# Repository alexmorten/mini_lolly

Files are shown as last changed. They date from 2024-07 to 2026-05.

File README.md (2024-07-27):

# Mini Lolly

## Run the Simulator

Run any kind of static file server in the repo root to run the simulator.
For example, you can use the following commands as a server:

```bash
python -m http.server 8000
# or 
ruby -run -ehttpd . -p8000
```

Access the simulator by visiting http://localhost:8000 in your browser.

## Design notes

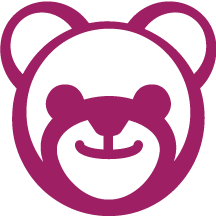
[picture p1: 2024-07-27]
simulator/img/teddyhead-maroontransparent.png

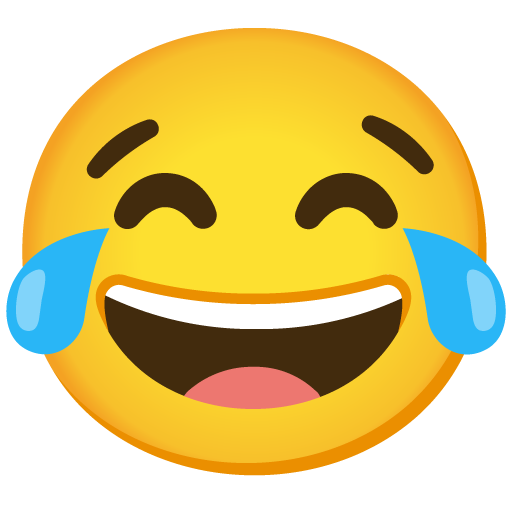
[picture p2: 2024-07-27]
simulator/img/face-with-tears-of-joy.png

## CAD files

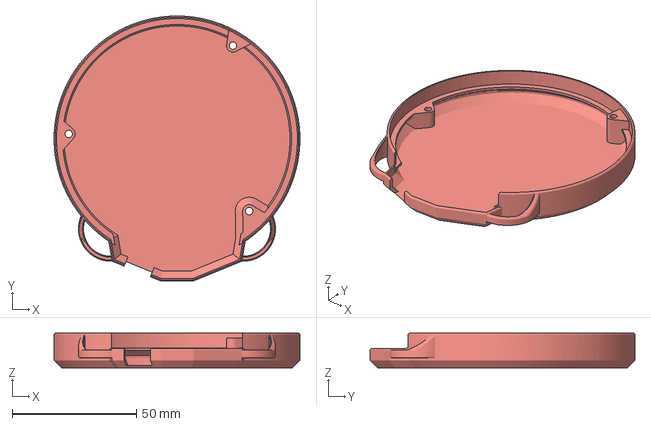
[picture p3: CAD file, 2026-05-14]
printing/housing.3mf
98.8 x 106.5 x 14.0 mm

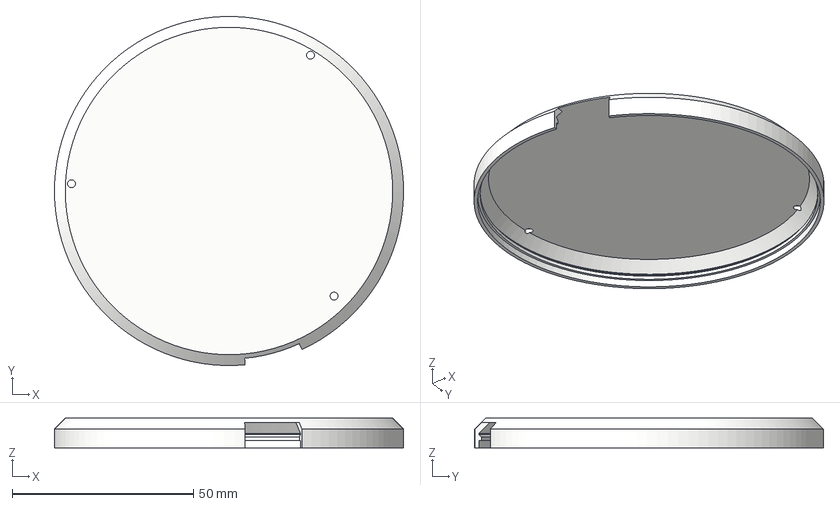
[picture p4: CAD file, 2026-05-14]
printing/diffuser.3mf
96.4 x 96.4 x 8.20 mm

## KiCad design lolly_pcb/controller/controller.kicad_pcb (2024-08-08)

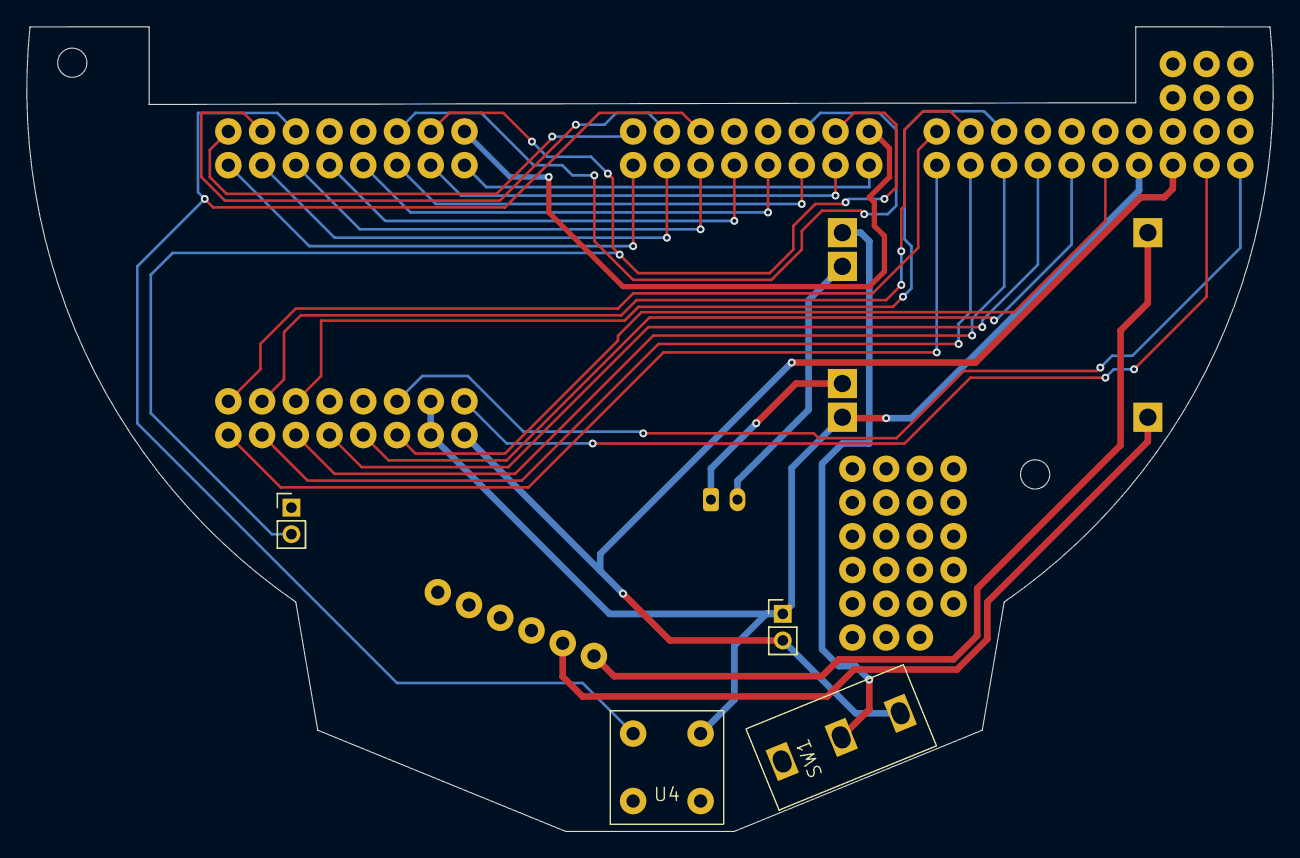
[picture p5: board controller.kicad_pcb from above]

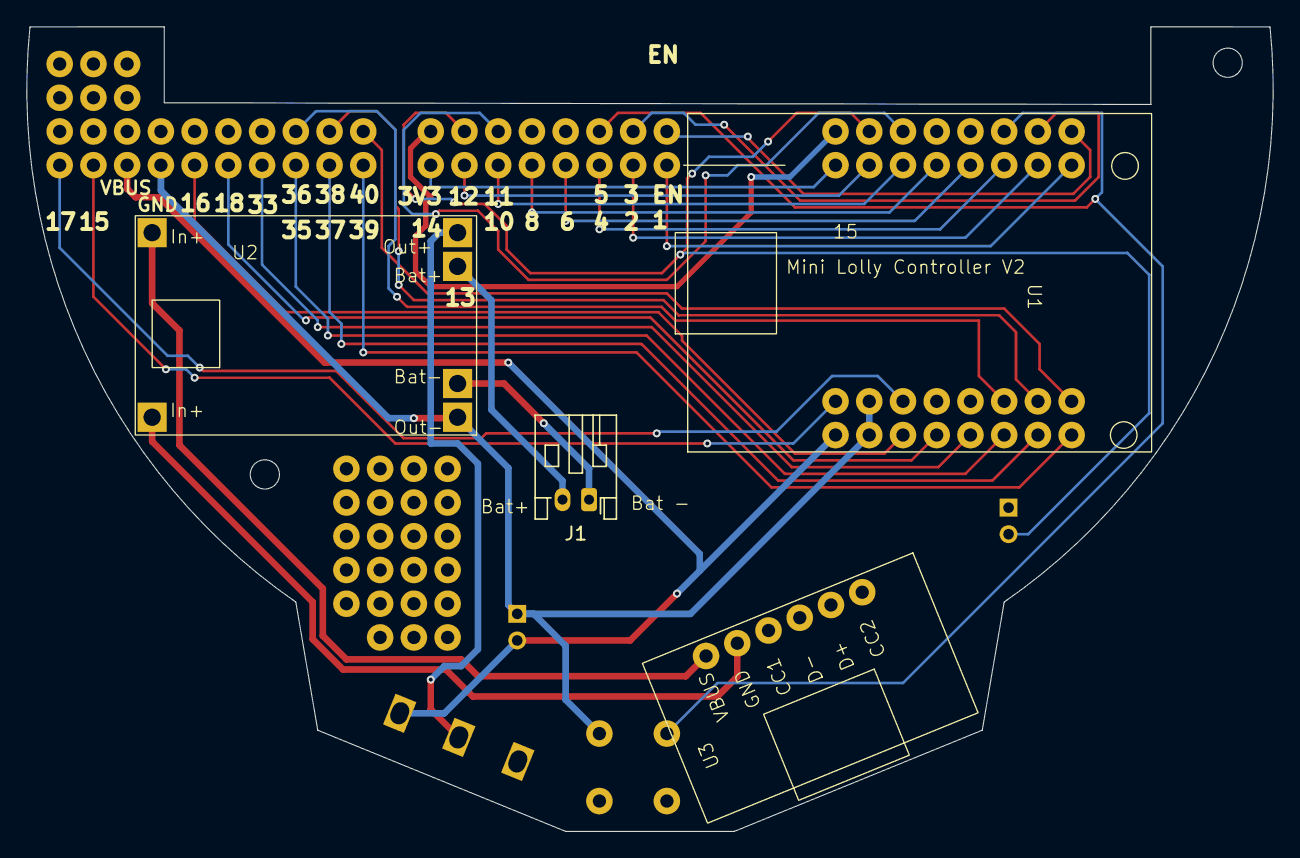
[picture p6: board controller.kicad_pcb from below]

Board: 2 copper layers, 93.8 x 60.6 mm, 6 parts (4 on the bottom side), 8 nets.

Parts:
J1: Conn_01x02_Pin; JST_PH_S2B-PH-K_1x02_P2.00mm_Horizontal
SW1: SW_SPDT; 1P2T SPDT RUNCCI-YUN
U1: ESP32-S2-MINI-1; esp32 s2-mini dev board
U2: tp4056 module
U3: usb-c 5v breakout
U4: small thoughhole button

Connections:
5: U1.5 (GPIO5/ADC1_CH4), U4.1 (In1)
Bat+: J1.2, U2.5 (Bat_+)
Bat-: J1.1, U2.6 (Bat_-)
GND: U1.GND, U2.4 (Out_-), U4.3 (Out1)
unnamed: SW1.2 (B), U2.3 (Out_+)
unnamed: U2.1 (In_+), U3.1 (VBUS)
unnamed: U2.2 (In_-), U3.2 (GND)
VBUS: SW1.3 (C), U1.VBUS

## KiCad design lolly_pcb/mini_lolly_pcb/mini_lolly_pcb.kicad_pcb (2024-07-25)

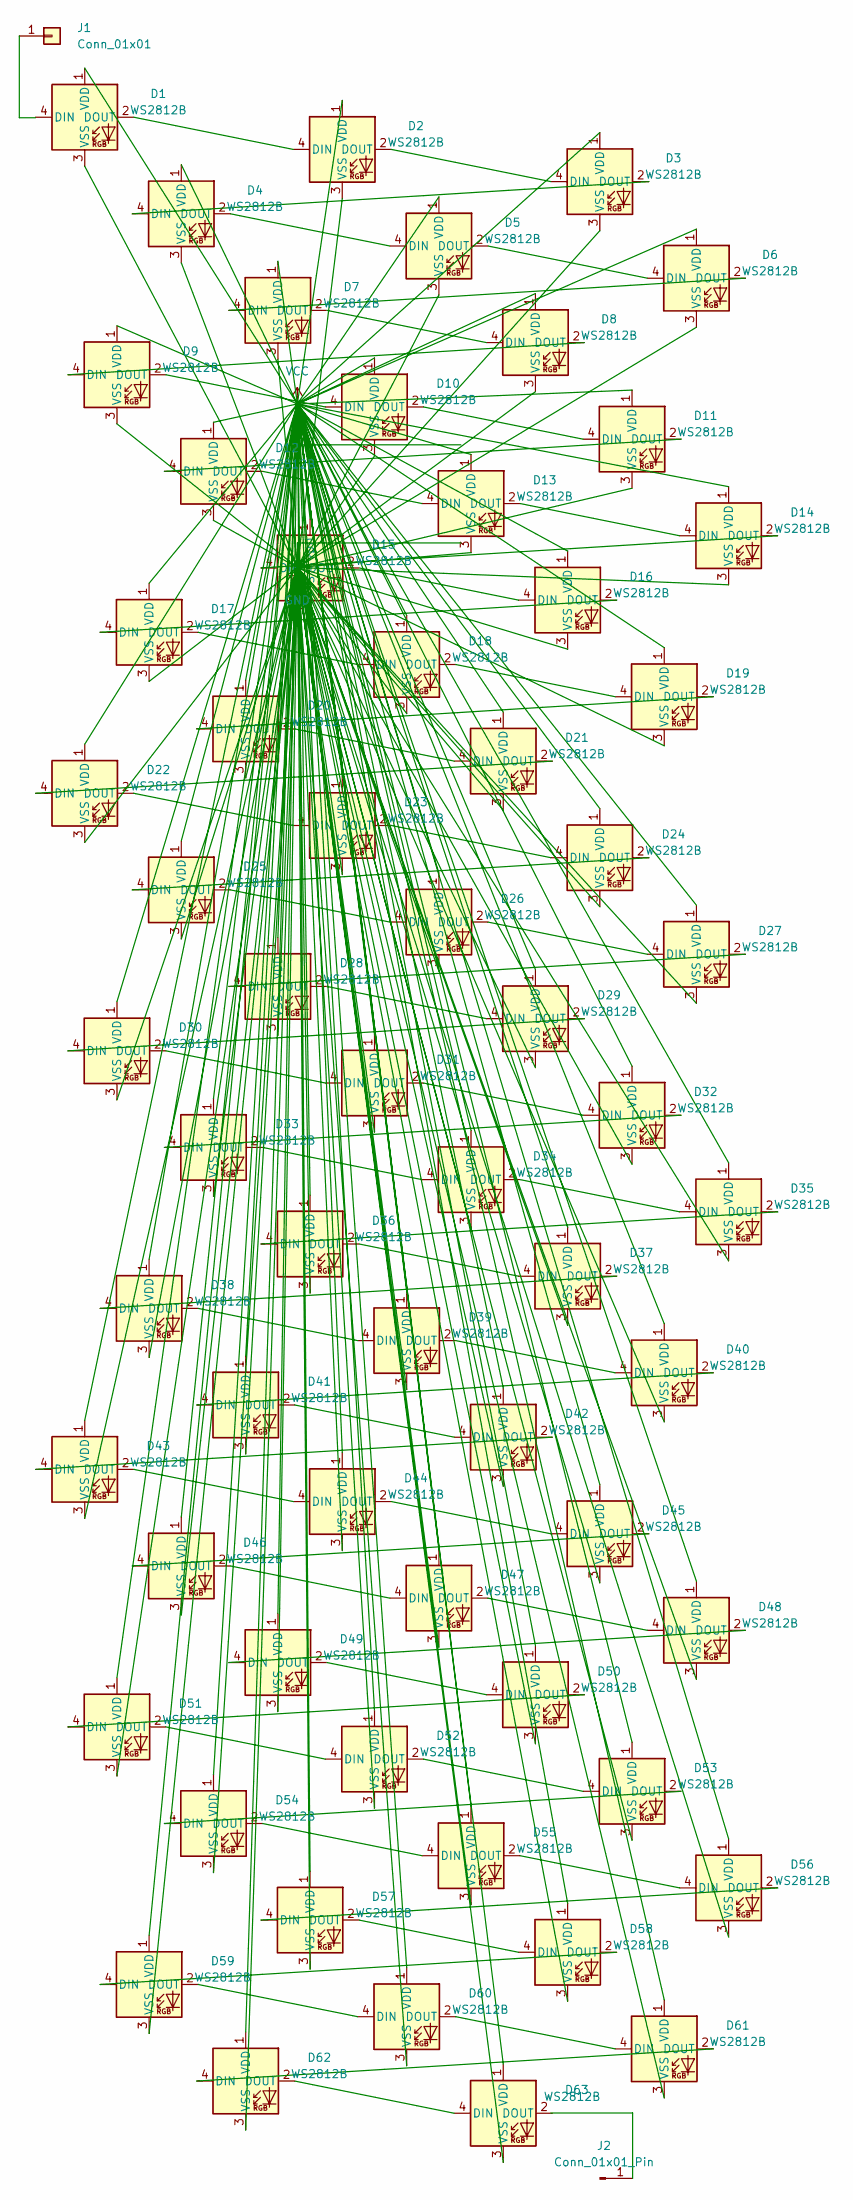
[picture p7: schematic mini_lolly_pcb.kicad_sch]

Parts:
D1, D2, D3, D4, D5, D6, D7, D8, D9, D10, D11, D12, D13, D14, D15, D16, D17, D18, D19, D20, D21, D22, D23, D24, D25, D26, D27, D28, D29, D30, D31, D32, D33, D34, D35, D36, D37, D38, D39, D40, D41, D42, D43, D44, D45, D46, D47, D48, D49, D50, D51, D52, D53, D54, D55, D56, D57, D58, D59, D60, D61, D62, D63: WS2812B; LED_WS2812B_PLCC4_5.0x5.0mm_P3.2mm
J1: Conn_01x01
J2: Conn_01x01_Pin

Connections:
unnamed: D1.2 (DOUT), D2.4 (DIN)
unnamed: D2.2 (DOUT), D3.4 (DIN)
unnamed: D3.2 (DOUT), D4.4 (DIN)
unnamed: D4.2 (DOUT), D5.4 (DIN)
unnamed: D5.2 (DOUT), D6.4 (DIN)
unnamed: D6.2 (DOUT), D7.4 (DIN)
unnamed: D7.2 (DOUT), D8.4 (DIN)
unnamed: D8.2 (DOUT), D9.4 (DIN)
unnamed: D9.2 (DOUT), D10.4 (DIN)
unnamed: D10.2 (DOUT), D11.4 (DIN)
unnamed: D11.2 (DOUT), D12.4 (DIN)
unnamed: D12.2 (DOUT), D13.4 (DIN)
unnamed: D13.2 (DOUT), D14.4 (DIN)
unnamed: D14.2 (DOUT), D15.4 (DIN)
unnamed: D15.2 (DOUT), D16.4 (DIN)
unnamed: D16.2 (DOUT), D17.4 (DIN)
unnamed: D17.2 (DOUT), D18.4 (DIN)
unnamed: D18.2 (DOUT), D19.4 (DIN)
unnamed: D19.2 (DOUT), D20.4 (DIN)
unnamed: D20.2 (DOUT), D21.4 (DIN)
unnamed: D21.2 (DOUT), D22.4 (DIN)
unnamed: D22.2 (DOUT), D23.4 (DIN)
unnamed: D23.2 (DOUT), D24.4 (DIN)
unnamed: D24.2 (DOUT), D25.4 (DIN)
unnamed: D25.2 (DOUT), D26.4 (DIN)
unnamed: D26.2 (DOUT), D27.4 (DIN)
unnamed: D27.2 (DOUT), D28.4 (DIN)
unnamed: D28.2 (DOUT), D29.4 (DIN)
unnamed: D29.2 (DOUT), D30.4 (DIN)
unnamed: D30.2 (DOUT), D31.4 (DIN)
unnamed: D31.2 (DOUT), D32.4 (DIN)
unnamed: D32.2 (DOUT), D33.4 (DIN)
unnamed: D33.2 (DOUT), D34.4 (DIN)
unnamed: D34.2 (DOUT), D35.4 (DIN)
unnamed: D35.2 (DOUT), D36.4 (DIN)
unnamed: D36.2 (DOUT), D37.4 (DIN)
unnamed: D37.2 (DOUT), D38.4 (DIN)
unnamed: D38.2 (DOUT), D39.4 (DIN)
unnamed: D39.2 (DOUT), D40.4 (DIN)
unnamed: D40.2 (DOUT), D41.4 (DIN)
unnamed: D41.2 (DOUT), D42.4 (DIN)
unnamed: D42.2 (DOUT), D43.4 (DIN)
unnamed: D43.2 (DOUT), D44.4 (DIN)
unnamed: D44.2 (DOUT), D45.4 (DIN)
unnamed: D45.2 (DOUT), D46.4 (DIN)
unnamed: D46.2 (DOUT), D47.4 (DIN)
unnamed: D47.2 (DOUT), D48.4 (DIN)
unnamed: D48.2 (DOUT), D49.4 (DIN)
unnamed: D49.2 (DOUT), D50.4 (DIN)
unnamed: D50.2 (DOUT), D51.4 (DIN)
unnamed: D51.2 (DOUT), D52.4 (DIN)
unnamed: D52.2 (DOUT), D53.4 (DIN)
unnamed: D53.2 (DOUT), D54.4 (DIN)
unnamed: D54.2 (DOUT), D55.4 (DIN)
unnamed: D55.2 (DOUT), D56.4 (DIN)
unnamed: D56.2 (DOUT), D57.4 (DIN)
unnamed: D57.2 (DOUT), D58.4 (DIN)
unnamed: D58.2 (DOUT), D59.4 (DIN)
unnamed: D59.2 (DOUT), D60.4 (DIN)
unnamed: D60.2 (DOUT), D61.4 (DIN)
unnamed: D61.2 (DOUT), D62.4 (DIN)
unnamed: D62.2 (DOUT), D63.4 (DIN)

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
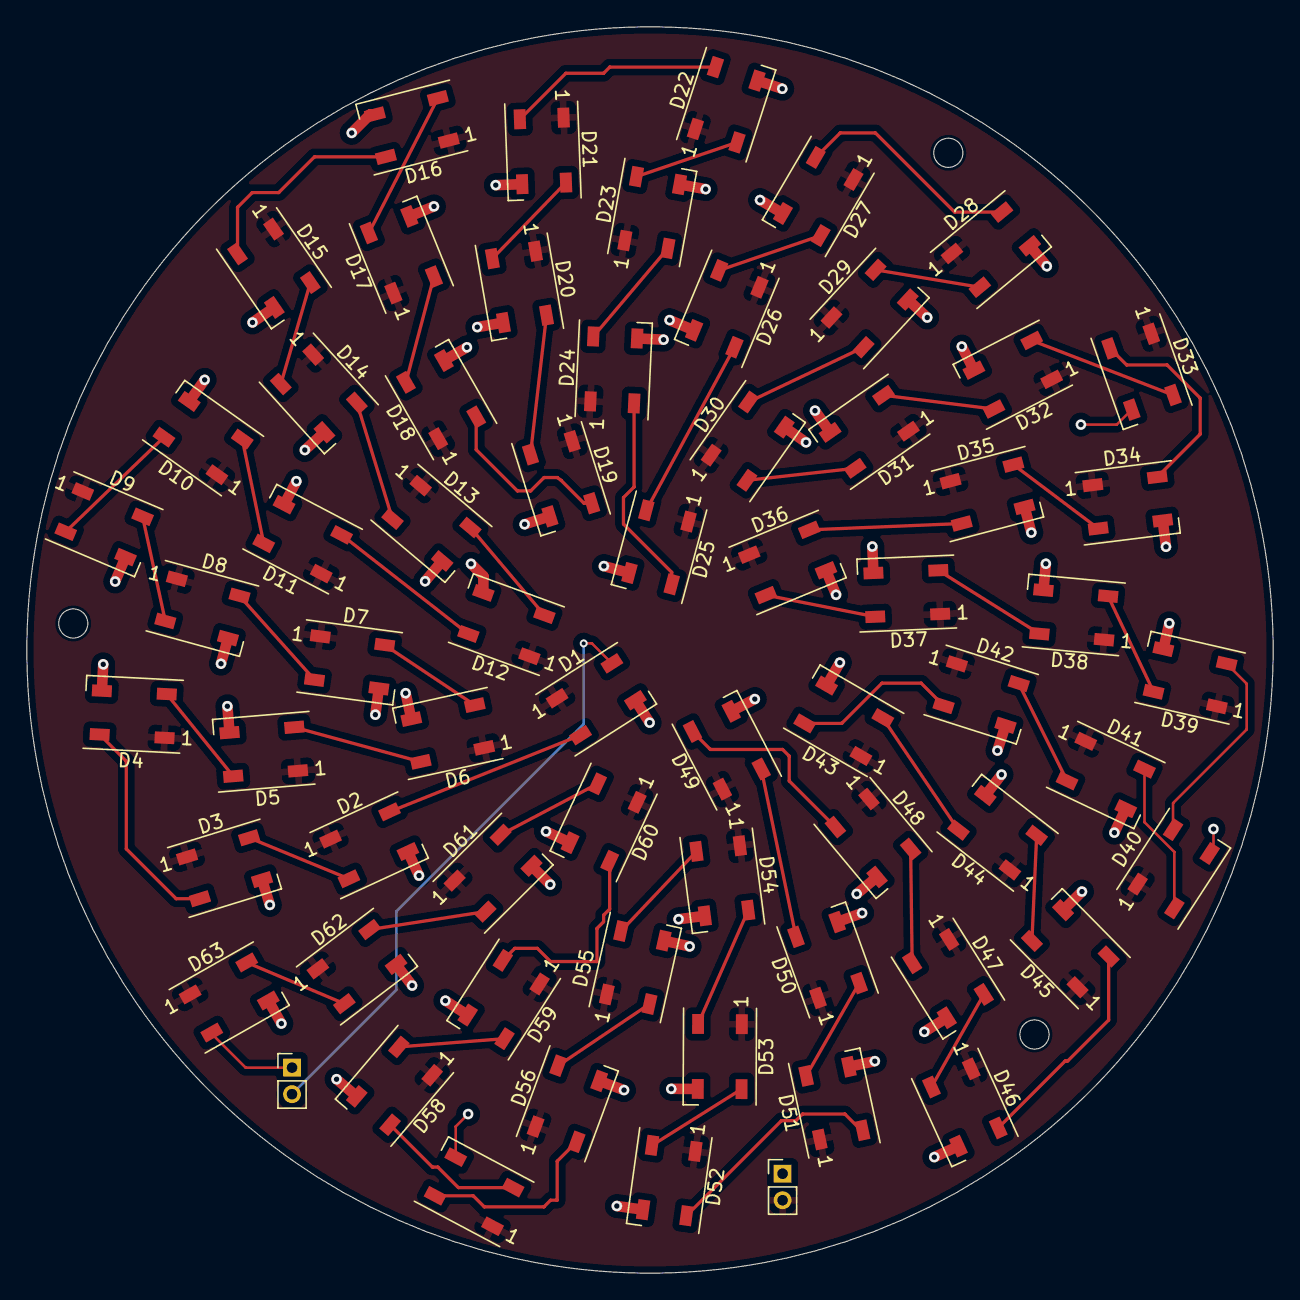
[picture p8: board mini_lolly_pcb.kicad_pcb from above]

Board: 2 copper layers, 94.0 x 94.0 mm, 63 parts (0 on the bottom side), 64 nets.

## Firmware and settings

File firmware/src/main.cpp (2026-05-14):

#include "FastLED.h"
#include "led_config.h"
#include "animations/twinkle_fox.h"
#include "animations/fire2012.h"
#include "animations/cylon.h"
#include "animations/demo_reel.h"
#include "animations/rings.h"
#include "animations/polar_rings.h"

// Replace with your network credentials
const char *ssid = "MiniLolly Manfred";
const char *password = "Lumos2024";

#define VOLTS 5
#define MAX_MA 200

#define NUM_BUTTONS 2
#define LED_BOARD 15
int buttonPins[NUM_BUTTONS] = {0, 5};

#define ARRAY_SIZE(A) (sizeof(A) / sizeof((A)[0]))

CRGBArray<NUM_LEDS> leds;

uint8_t brightness = 15;

void setBrightness(uint8_t b) {
    brightness = constrain(b, 1, 255);
    FastLED.setBrightness(brightness);
}

int buttonStates[NUM_BUTTONS] = {LOW};
int lastButtonStates[NUM_BUTTONS] = {LOW};
unsigned long lastDebounceTimes[NUM_BUTTONS] = {0};
String buttonNames[NUM_BUTTONS] = {"Board"};

#define debounceDelay 50

bool checkButton(int buttonIndex)
{
    bool buttonPressed = false;
    // read the state of the switch into a local variable:
    int reading = digitalRead(buttonPins[buttonIndex]);

    // check if the button has been pressed (i.e., reading is different from lastButtonState)
    if (reading != lastButtonStates[buttonIndex])
    {
        // reset the debouncing timer
        lastDebounceTimes[buttonIndex] = millis();
    }

    if ((millis() - lastDebounceTimes[buttonIndex]) > debounceDelay)
    {
        // whatever the reading is at, it's been there for longer than the debounce delay
        // so take it as the actual current state:
        if (reading != buttonStates[buttonIndex])
        {
            buttonStates[buttonIndex] = reading;

            // only toggle the LED if the new button state is HIGH
            if (buttonStates[buttonIndex] == LOW)
            {
                Serial.print("button ");
                Serial.print(buttonNames[buttonIndex]);
                Serial.println(" pressed");
                digitalWrite(LED_BOARD, !digitalRead(LED_BOARD));
                buttonPressed = true;
            }
        }
    }

    // save the reading. Next time through the loop, it'll be the lastButtonState:
    lastButtonStates[buttonIndex] = reading;

    return buttonPressed;
}

int patternIndex = 0;

// ============================ WIFI code ============================
// https://randomnerdtutorials.com/esp32-access-point-ap-web-server/

/*********
  Rui Santos
  Complete project details at https://randomnerdtutorials.com
*********/

// Load Wi-Fi library
#include <WiFi.h>

// Set web server port number to 80
WiFiServer server(80);

// Variable to store the HTTP request
String header;

void setupWifi()
{
    // Connect to Wi-Fi network with SSID and password
    Serial.print("Setting AP (Access Point)…");
    // Remove the password parameter, if you want the AP (Access Point) to be open
    WiFi.softAP(ssid, password);

    IPAddress IP = WiFi.softAPIP();
    // The network established by softAP will have default IP address of 192.168.4.1. This address may be changed using softAPConfig (see below).
    Serial.print("AP IP address: ");
    Serial.println(IP);

    server.begin();
}

// array of strings with pattern names
String patterns[] = {
    // "Twinkle Fox",
"Polar Radial",
"Rainbow with Glitter",
    "Rings",
    //  "Fire2012",
     // "Cylon",
"Polar Rings",
"Polar Spiral",
// "Rainbow",
// "Confetti",
// "Sinelon",
// "Juggle",
// "BPM"
};

const int numPatterns = ARRAY_SIZE(patterns);

void (*patternFunctions[])() = {
    // loopTwinkleFox,
    loopPolarRingsRadial,
    loopRainbowWithGlitter,
    loopRings,
    // loopFire2012,
    // loopCylon,
    loopPolarRings,
    loopPolarRingsSpiral,
    // loopRainbow,
    // loopConfetti,
    // loopSinelon,
    // loopJuggle,
    // loopBpm,
};

void checkHTTPRequest()
{
    for (int i = 0; i < ARRAY_SIZE(patterns); i++)
    {
        if (header.indexOf("GET /" + String(i) + "/on") >= 0)
        {
            Serial.println(patterns[i]);
            patternIndex = i;
        }
    }
    
    // Check for brightness control
    int brightnessIndex = header.indexOf("GET /brightness/");
    if (brightnessIndex >= 0) {
        int valueStart = brightnessIndex + 16; // Length of "GET /brightness/"
        int valueEnd = header.indexOf(" ", valueStart);
        if (valueEnd == -1) valueEnd = header.indexOf("\n", valueStart);
        if (valueEnd > valueStart) {
            String valueStr = header.substring(valueStart, valueEnd);
            int newBrightness = valueStr.toInt();
            setBrightness(newBrightness);
            Serial.print("Brightness set to: ");
            Serial.println(brightness);
        }
    }
}

void renderBrightnessControlsHTML(WiFiClient *client)
{
    client->println("<h2>Brightness: " + String(brightness) + "</h2>");
    
    int brightnessLevels[] = {5, 10, 15, 20, 25, 50};
    int numLevels = 6;
    
    for (int i = 0; i < numLevels; i++)
    {
        client->print("<a href=\"/brightness/" + String(brightnessLevels[i]) + "\"><button class=\"");
        if (brightness == brightnessLevels[i]) {
            client->print("button");
        } else {
            client->print("button button2");
        }
        client->println("\">" + String(brightnessLevels[i]) + "</button></a>");
    }
}

void renderButtonsHTML(WiFiClient *client)
{
    for (int i = 0; i < ARRAY_SIZE(patterns); i++)
    {
        // Display current state, and ON/OFF buttons for GPIO 26
        client->println("<p>" + patterns[i]);
        // If the output26State is off, it displays the ON button
        if (patternIndex == i)
        {
            client->println(" <a href=\"/" + String(i) + "/on\"><button class=\"button\">ON</button></a></p>");
        }
        else
        {
            client->println(" <a href=\"/" + String(i) + "/on\"><button class=\"button button2\">ON</button></a></p>");
        }
    }
}

void loopWifi()
{
    WiFiClient client = server.available(); // Listen for incoming clients

    if (client)
    { // If a new client connects,
        unsigned long startMillis = millis();
        // Serial.println("connected"); // print a message out in the serial port
        String currentLine = ""; // make a String to hold incoming data from the client
        while (client.connected())
        { // loop while the client's connected
            if (client.available())
            {                           // if there's bytes to read from the client,
                char c = client.read(); // read a byte, then
                // Serial.write(c);        // print it out the serial monitor
                header += c;
                if (c == '\n')
                { // if the byte is a newline character
                    // if the current line is blank, you got two newline characters in a row.
                    // that's the end of the client HTTP request, so send a response:
                    if (currentLine.length() == 0)
                    {
                        // HTTP headers always start with a response code (e.g. HTTP/1.1 200 OK)
                        // and a content-type so the client knows what's coming, then a blank line:
                        client.println("HTTP/1.1 200 OK");
                        client.println("Content-type: text/html");
                        client.println("Connection: close");
                        client.println();

                        checkHTTPRequest();

                        // Display the HTML web page
                        client.println("<!DOCTYPE html><html>");
                        client.println("<head><meta name=\"viewport\" content=\"width=device-width, initial-scale=1\">");
                        client.println("<link rel=\"icon\" href=\"data:,\">");
                        // CSS to style the on/off buttons
                        // Feel free to change the background-color and font-size attributes to fit your preferences
                        client.println("<style>html { font-family: Helvetica; display: inline-block; margin: 0px auto; text-align: center;}");
                        client.println(".button { background-color: #4CAF50; border: none; color: white; padding: 4px 20px;");
                        client.println("text-decoration: none; font-size: 20px; margin: 2px; cursor: pointer;}");
                        client.println(".button2 {background-color: #555555;}</style></head>");

                        // Web Page Heading
                        client.println("<body><h1>MiniLolly Remote</h1>");

                        renderButtonsHTML(&client);
                        
                        renderBrightnessControlsHTML(&client);

                        client.println("</body></html>");

                        // The HTTP response ends with another blank line
                        client.println();
                        // Break out of the while loop
                        break;
                    }
                    else
                    { // if you got a newline, then clear currentLine
                        currentLine = "";
                    }
                }
                else if (c != '\r')
                {                     // if you got anything else but a carriage return character,
                    currentLine += c; // add it to the end of the currentLine
                }
            }
        }
        // Clear the header variable
        header = "";
        // Close the connection
        client.stop();
        Serial.print("request took ");
        Serial.print(millis() - startMillis);
        Serial.println("ms");
    }
}

// ============================ WIFI code ============================

void setup()
{
    Serial.begin(115200);
    Serial.println("initialized");

    pinMode(LED_BOARD, OUTPUT);

    for (int i = 0; i < NUM_BUTTONS; i++)
    {
        pinMode(buttonPins[i], INPUT_PULLUP);
    }

    // start with the LED off
    digitalWrite(LED_BOARD, LOW);

    delay(3000); // safety startup delay

    setupWifi();

    // FastLED.setMaxPowerInVoltsAndMilliamps(VOLTS, MAX_MA);
    FastLED.addLeds<LED_TYPE, LED_DATA_PIN, COLOR_ORDER>(leds, NUM_LEDS)
        .setCorrection(TypicalLEDStrip);
    
    setBrightness(brightness);
}

void loop()
{
    bool buttonPressedESP = checkButton(0);
    bool buttonPressedExternal = checkButton(1);
    if (buttonPressedESP || buttonPressedExternal)
    {
        patternIndex++;
        if (patternIndex > (numPatterns - 1))
        {
            patternIndex = 0;
        }
    }

    if (patternIndex >= 0 && patternIndex < numPatterns)
    {
        patternFunctions[patternIndex]();
    }

    loopWifi();
}

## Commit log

2024-07-24 init commit
    [lolly.kicad_sch, mini_lolly_pcb.kicad_pcb, mini_lolly_pcb.kicad_sch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]
2024-07-24 add tracks and vias
    [mini_lolly_pcb.kicad_pcb, mini_lolly_pcb.kicad_sch]
2024-07-24 somewhat working version
    [mini_lolly_pcb.kicad_sch]
2024-07-25 rotate outermost leds for space
    [controller_pcb.kicad_pcb, mini_lolly_pcb.kicad_pcb, mini_lolly_pcb.kicad_sch]
2024-07-26 add HTML canvas lolly simulator (so far only draws blurred static LEDs)
2024-07-26 apply clipping and brightness filter for lighter colors
2024-07-27 fix blurry LED drawing performance problem, back at smooth 120FPS (frame time 2.5ms on M1 Pro)
2024-07-27 also allow simulating the big 512 LED lolly
2024-07-27 add esp32 s3-mini as controller
    [controller.kicad_pcb, controller.kicad_sch, controller_pcb.kicad_pcb]
2024-07-27 add charging circuit, connector and switch
    [controller.kicad_pcb, controller.kicad_sch]
2024-07-27 make animation pausable (laptop battery thanks you)
2024-07-27 first proper layout
    includes solder pads for later components, better antenna placement, and routing
    [controller.kicad_pcb, controller.kicad_sch]
2024-07-27 better board outline
    [controller.kicad_pcb]
2024-07-29 fix missing connection
    [controller.kicad_pcb]
2024-08-03 add proper usb-c 5v breakdout board
    the charging circuit does not have the pull down resistors on the proper pins to get 5v from usb-c PD
2024-08-03 rearrange board for usb-c breakout board
    [controller.kicad_pcb, controller.kicad_sch]
2024-08-03 add labels
    [controller.kicad_pcb]
2024-08-03 fix label too close to hole
    [controller.kicad_pcb]
2024-08-04 use pin no. 5 for button
    [controller.kicad_pcb, controller.kicad_sch]
2024-08-06 implement color rings demo from current controller firmware
2024-08-06 add control CSS layout with pattern switcher
2024-08-08 fix controller hole positions and sizes
    [controller.kicad_pcb]
2024-08-12 join twinkle fox example and color ring demo, cycle them with the board button (pin 0)
2024-08-12 switch to different board, so that hands free programming works
2024-08-12 add a WIFI AP with a web server that can switch between patterns
2024-08-20 nicer UI HTML with more compact pattern button layout
2024-08-21 add physical button to pattern switching, disable Cylon because it doesn't have a fast loop
    [main.cpp]
2025-07-09 use led_config
2025-07-09 fix pin
2026-05-14 update pcb files
2026-05-14 add printing files
    [diffuser.3mf, housing.3mf]
